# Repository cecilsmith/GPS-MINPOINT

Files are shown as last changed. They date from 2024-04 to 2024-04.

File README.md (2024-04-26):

# GPS-MINPOINT

This is the project folder for a Spring 2024 EE2361 Final Project.

## Hardware List

- Air530 GPS Module (connected via UART)
- PIC24 Microcontroller
- LCD for User Interaction
- LEDs for Debugging
- Printed/Milled Circuit Board for Components
- Enclosure for Electronics and Antenna
- Power Supply (3.3V)

## Software Requirements

- GPS driver ([`gps.h`](/2_Code/src/gps.h)/[`gps.c`](/2_Code/src/gps.c)) to interface with GPS module via UART
- UART driver ([`uart.h`](/2_Code/src/uart.h)/[`uart.c`](/2_Code/src/uart.c)) to handle communication with GPS module
- LCD driver ([`lcd.h`](/2_Code/src/lcd.h)/[`lcd.c`](/2_Code/src/lcd.c)) to handle communication with LCD module
- Mathematical Formulae ([`calculations.h`](/2_Code/src/calculations.h)/[`calculations.c`](/2_Code/src/calculations.c)) to find useful information from GPS coordinates
- General Use Functions ([`utils.h`](/2_Code/src/utils.h)/[`utils.c`](/2_Code/src/utils.c)) to contain non-standard, yet generally useful functions
- [`main.c`](/2_Code/src/main.c) to initialize hardware, call GPS driver to get location data, process data to find location

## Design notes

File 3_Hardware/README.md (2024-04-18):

# Hardware

This folder contains all work and documentation regarding the hardware. 

For this project, a custom PCB was designed using KiCAD. All footprints, schematics, and 3D files can be found under the `/lib/` folder.

### Current Design:
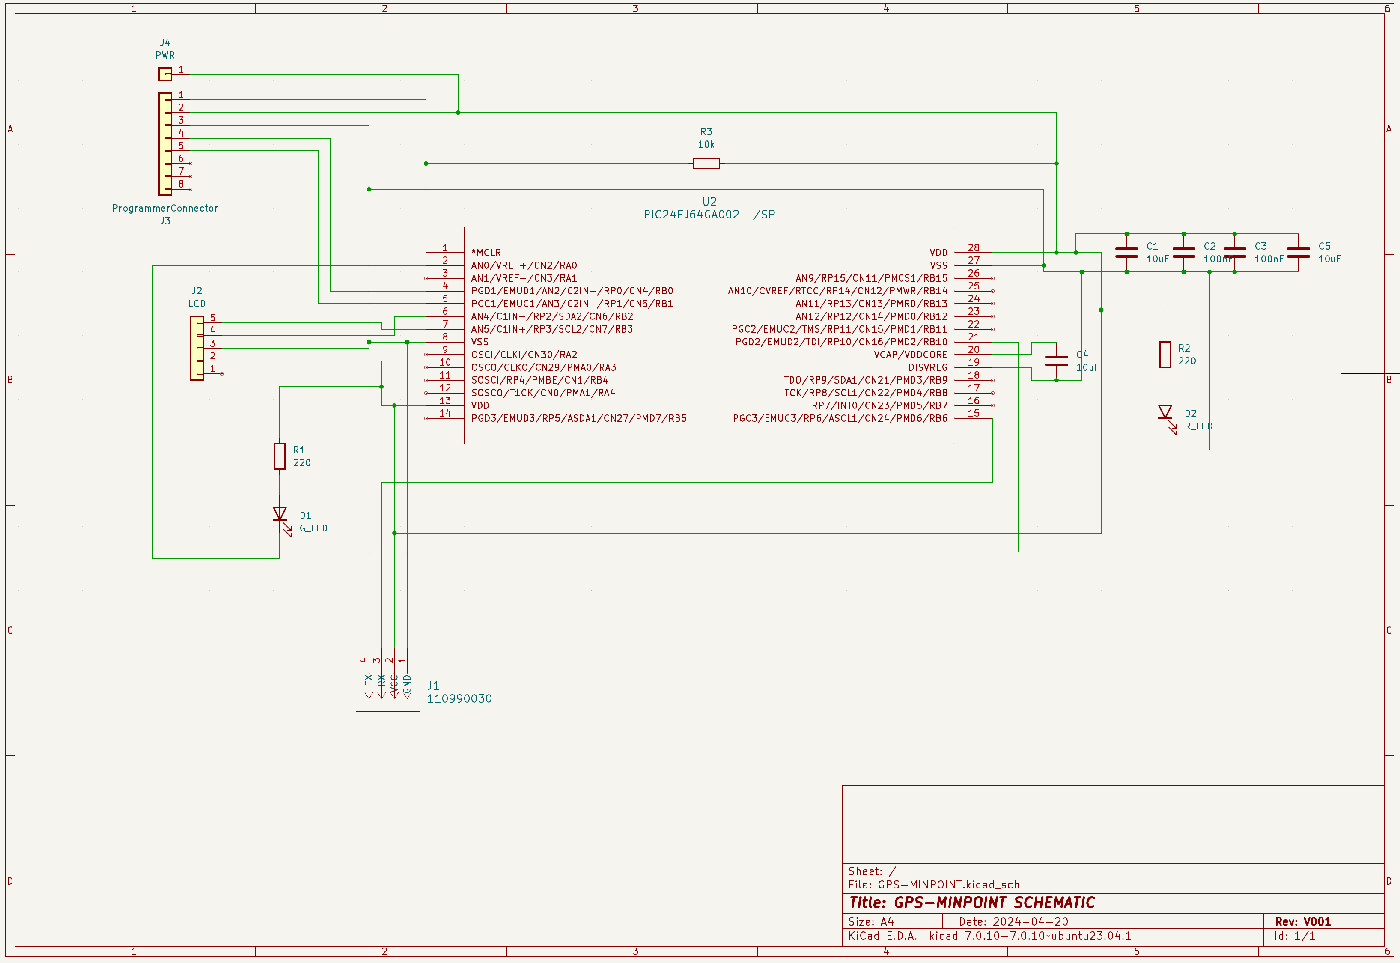
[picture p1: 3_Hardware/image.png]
Current Schematic Layout


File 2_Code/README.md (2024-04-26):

# Code

All source code for the project is located in this folder.

## Layout
- `/src` - Source code for the project.
  - `uart.h/uart.c` - UART driver.
  - `gps.h/gps.c` - GPS driver, uses UART driver.
  - `utils.h/utils.c` - General use functions
  - `calculations.h/calculations.c` - Reponsible for GPS distance and bearing calculation
  - `lcd.h/lcd.c` - LCD driver
  - `main.c` - Main file for the project.
- `/test` - Unit tests for the project.

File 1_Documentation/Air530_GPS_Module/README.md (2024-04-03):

# Air530 GPS Module

## Overview
The GPS module uses the NMEA protocol to communicate with the GPS receiver. This happens over a UART communication interface with the PIC24.

Based on the provided data sheets, the GPS module's UART runs at `9600 baud`.

## NMEA Protocol
The following link is a useful resource for understanding the NMEA protocol: [GPS NMEA](https://docs.arduino.cc/learn/communication/gps-nmea-data-101/)

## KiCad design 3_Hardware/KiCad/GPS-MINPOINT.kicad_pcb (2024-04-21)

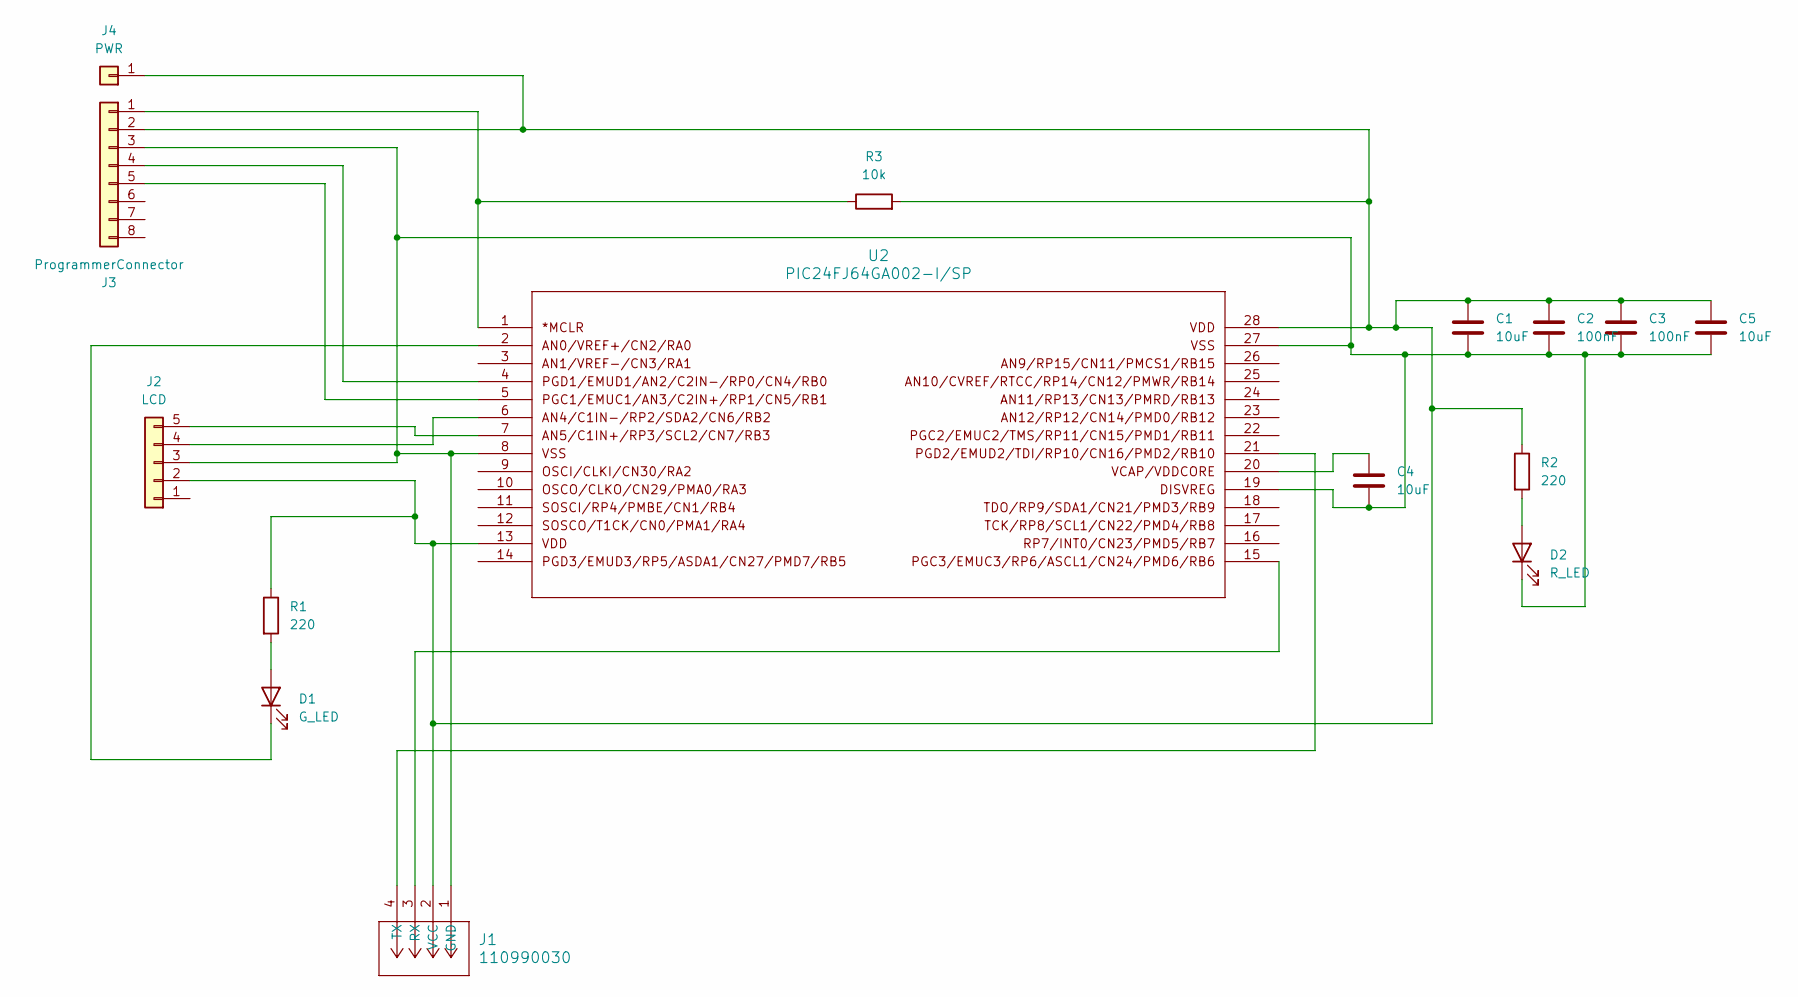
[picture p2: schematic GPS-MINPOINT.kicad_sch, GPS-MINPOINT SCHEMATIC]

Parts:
C1, C4, C5: 10uF; C_Disc_D4.7mm_W2.5mm_P5.00mm
C2, C3: 100nF; C_Disc_D4.7mm_W2.5mm_P5.00mm
D1: G_LED; LED_D3.0mm
D2: R_LED; LED_D3.0mm
J1: 110990030; CONN_110990030_SEE
J2: LCD; PinSocket_1x05_P2.54mm_Vertical
J3: ProgrammerConnector; PinHeader_1x08_P2.54mm_Vertical
J4: PWR; PinHeader_1x01_P2.54mm_Vertical
R1, R2: 220; R_Axial_DIN0207_L6.3mm_D2.5mm_P7.62mm_Horizontal
R3: 10k; R_Axial_DIN0207_L6.3mm_D2.5mm_P7.62mm_Horizontal
U2: PIC24FJ64GA002-I/SP; SPDIP28_300MC_MCH

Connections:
unnamed: C4.1, U2.20
unnamed: D1.2 (A), R1.2
unnamed: D1.1 (K), U2.2
unnamed: D2.2 (A), R2.2
unnamed: C1.2, C2.2, C3.2, C4.2, C5.2, D2.1 (K), J1.1 (GND), J2.3 (GND), J3.3, U2.8, U2.19, U2.27
unnamed: J1.3 (RX), U2.15
unnamed: J1.4 (TX), U2.21
unnamed: C1.1, C2.1, C3.1, C5.1, J1.2 (VCC), J2.2 (VDD), J3.2, J4.1, R1.1, R2.1, R3.2, U2.13, U2.28
unnamed: J2.5 (SCL), U2.7
unnamed: J2.4 (SDA), U2.6
unnamed: J3.1, R3.1, U2.1
unnamed: J3.4, U2.4
unnamed: J3.5, U2.5

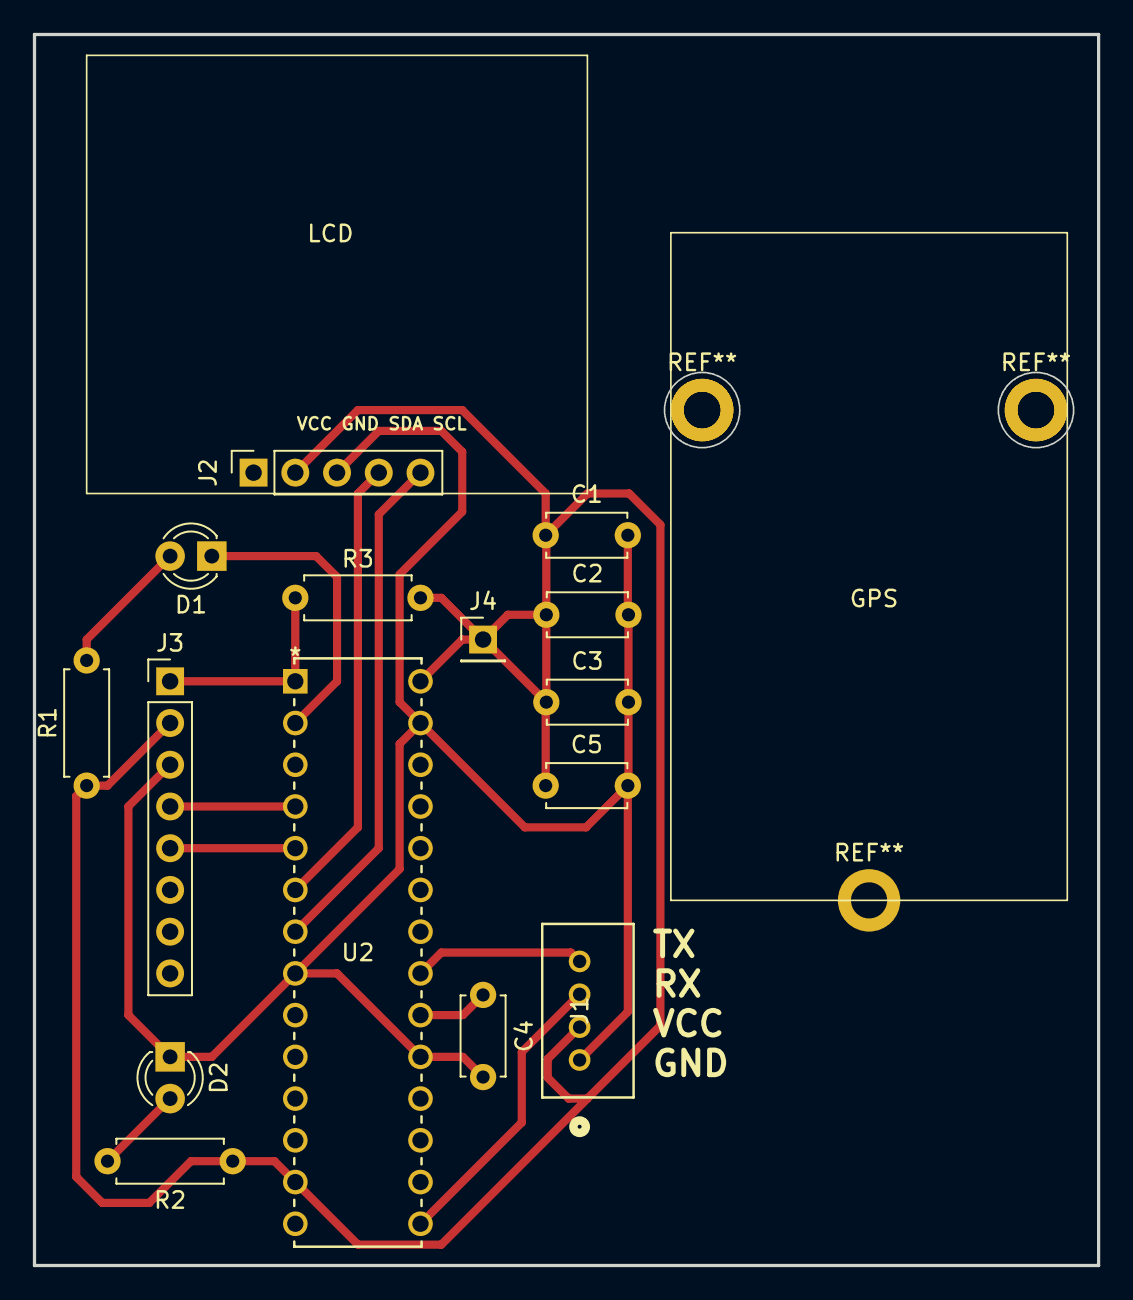
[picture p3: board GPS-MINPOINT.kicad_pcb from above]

Board: 2 copper layers, 64.8 x 74.9 mm, 15 parts (0 on the bottom side), 13 nets.

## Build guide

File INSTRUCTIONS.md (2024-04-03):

# GitHub Instructions

Here are the steps to use this repository with GitHub Desktop:

1. Install GitHub Desktop if you don't already have it:
   - Go to https://desktop.github.com/ and click on "Download for..." to download the version for your operating system.
   - Follow the installation prompts.

2. Clone the repository:
   - Open GitHub Desktop and click "File > Clone repository".
   - Enter the URL of this repository (`https://github.com/cecilsmith/GPS-MINPOINT.git`) and select a local path where you want the repository contents to be downloaded.
   - Click "Clone".
   
3. Make changes and commit:
   - Open the repository in your preferred text editor or IDE.
   - Make your changes to the files.
   - Go back to GitHub Desktop. You should see the changed files listed in the left panel.
   - If you haven't already, change your current branch to be something new/named after the changes you are working on--this will avoid accidental overwrites of the 'main' branch.
   - Enter a commit message summarizing your changes and then click "Commit to branch".
   
4. Push your changes:
   - In GitHub Desktop, click "Push origin" to push your committed changes to the remote repository on GitHub. 
   
5. Pull latest changes:
   - If someone else has modified the code click "Fetch origin" to retrieve them.
   - To merge the updates into your local repository, click "Pull origin".

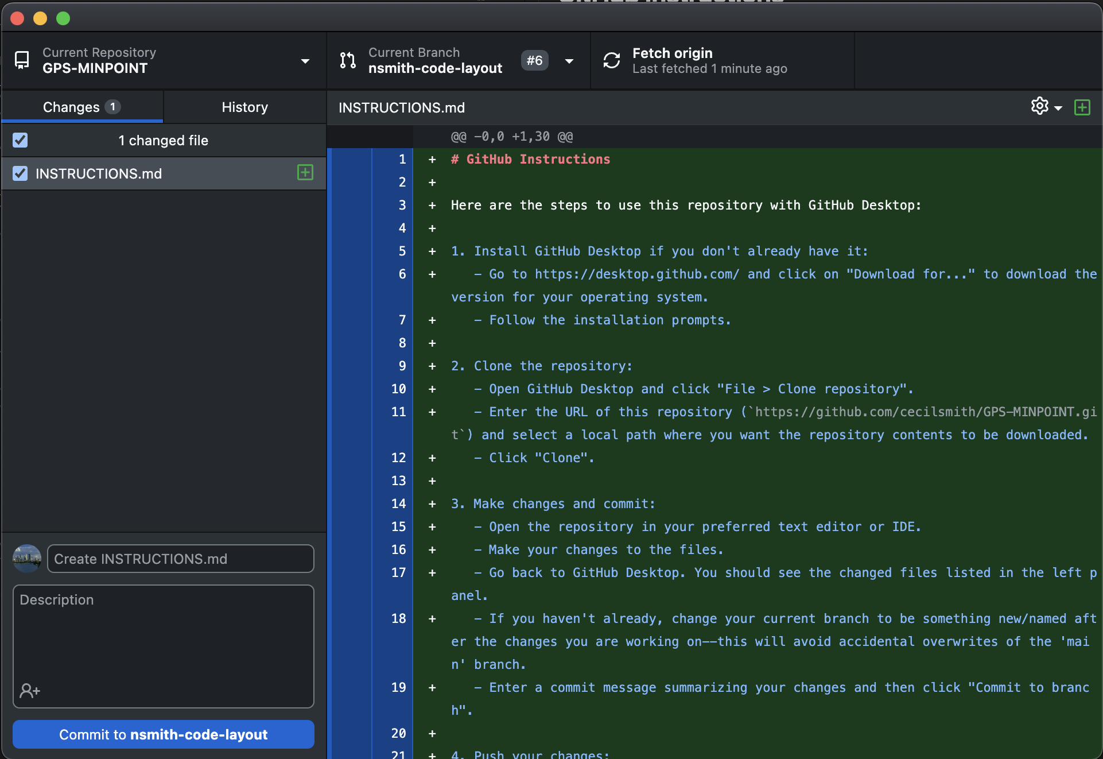
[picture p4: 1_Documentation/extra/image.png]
Sample window of GitHub Desktop


Now you have the repository on your local machine and can use GitHub Desktop to push and pull changes to sync with the remote repository on GitHub.

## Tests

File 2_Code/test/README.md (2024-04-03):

# Test

This folder is a designated spot for 'test code' to not clutter the main, `src` code.

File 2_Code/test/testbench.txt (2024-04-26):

Use this online compiler: https://www.onlinegdb.com/online_c_compiler
Copy and paste the code below:

#include <stdio.h>
#include <math.h>

// Global variables for current and destination coordinates
double currLatitude = 44.975755, currLongitude = -93.217189;
double destLatitude = 44.973828, destLongitude = -93.224746;

// Function to update current location (mocked for testing)
void getCurrentLocation(double* lat, double* lon) {
    *lat = currLatitude;
    *lon = currLongitude;
}

// Function to convert degrees to radians
double dToR(double degrees) {
    // Convert degrees to radians
    return degrees / 180.0 * M_PI;
}

// Function to calculate the distance between two points using Haversine formula
double distanceFinder() {
    // Radius of the Earth in kilometers
    const double R = 6371.0;

    // Convert latitude and longitude from degrees to radians
    double currLatRad = dToR(currLatitude);
    double currLonRad = dToR(currLongitude);
    double destLatRad = dToR(destLatitude);
    double destLonRad = dToR(destLongitude);

    // Haversine formula
    double dLat = destLatRad - currLatRad;
    double dLon = destLonRad - currLonRad;
    double a = sin(dLat / 2) * sin(dLat / 2) +
               cos(currLatRad) * cos(destLatRad) *
               sin(dLon / 2) * sin(dLon / 2);
    double c = 2 * atan2(sqrt(a), sqrt(1 - a));
    double distance = R * c;

    return distance;
}

int main() {
    // Calculate the distance to the destination
    double distance = distanceFinder();

    // Output the calculated distance
    printf("Distance to destination: %.2lf kilometers\n", distance);

    return 0;
}

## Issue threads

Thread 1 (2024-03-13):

Initial UART Library

cecilsmith, 2024-03-13:
In order to communicate with the Air530 GPS module, a UART library must be made. This library may be based off of in-class code and/or code found online for basic Serial communication.

When configuring the UART bus, a baud rate of `9600` will be used.
 The `TX` port of one device goes with the `RX` port of the other device.

_All images regarding Serial communication taken from [SparkFun](https://learn.sparkfun.com/tutorials/serial-communication/all): https://learn.sparkfun.com/tutorials/serial-communication/all_

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
Schematic of Serial/UART ports

If I'm not mistaken, UART uses _TTL serial signals_, this means that `HIGH` bits correspond to '1's and and `LOW` bits correspond to '0's in the bitstream. See the image below for endianness.

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

cecilsmith, 2024-03-22:
Using the datasheet of the PIC24, on page 163, we can find the setup registers for UART communication.

`BRGH`: Hight Baud Rate Enable Bit (0, 1)
`PDSEL`<1:0>:  Parity and Data Selection Bits:

* `11` = 9-bit data no parity
* `10` = 8-bit data, odd parity
* `01` = 8-bit data, even parity
* `00` = 8-bit data, no parity

`STSEL`: Stop Bit Selection Bit (`1`: Two Stop Bits, `0`: One Stop Bit)
`UARTEN`: UARTx Enable Bit (0, 1)

cecilsmith, 2024-03-22:
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

This of course, is using Peripheral Pin Select (PPS) for pin assignment.

cecilsmith, 2024-03-28:
I'm going to propose that we run our uC at 16 MHz.

Everything below has been shown in Discussion and/or around pg. 109 in the data sheet for PIC24 (specifically the PPS).

Using the equation for Baud Rate:
when `BRGH = 0`:

$UxBRG = \frac{Fcy}{16*Baud Rate}-1$

$UxBRG = \frac{16000000}{16*9600} - 1 = 103$

``` C
_TRISB6 = 0;  // U1TX output on RB6
_TRISB10 = 1; // U1RX input on RB10

U1MODE = 0;
U1MODEbits.BRGH = 0;
U1BRG = 103;
U1MODEbits.UEN = 0;
U1MODEbits.UARTEN = 0;
U1MODEbits.UTXEN = 1;

__builtin_write_OSCCONL(OSCCON & 0xBF); // unlock PPS
_RP6R = 0x0003;  // RB6->UART1:U1TX; Table 10-3 on pg. 109 of DS
_U1RXR = 10;         // RB10->UART1:U1RX;
__builtin_write_OSCCONL(OSCCON | 0x40); // lock   PPS

IFS0bits.U1RXIF = 0;
IEC0bits.U1RXIE = 1;
```

cecilsmith, 2024-04-09:
UART library written and merged into codebase,

Closed 2024-04-09.

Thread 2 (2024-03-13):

Schematic/Wiring Diagram for MINPOINT Package

cecilsmith, 2024-03-13:
Using the information listed in the datasheets for the PIC24 microcontroller, a schematic must be made of the system.

This schematic ought to include all of the following:
* Microcontroller (PIC24)
* GPS (Air530)
* 8 LEDs for Navigation
* 1 LED for Completion

We may have to use multiplexing for the output LEDs given the limited number of available output pins.

cecilsmith, 2024-03-13:
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

cecilsmith, 2024-04-05:
The first push of the schematic/PCB has been started under [this branch](https://github.com/cecilsmith/GPS-MINPOINT/tree/hardware-schematic/3_Hardware).

If you are looking to replicate this, remember to correctly import all library files under `/lib/`.

cecilsmith, 2024-04-22:
Completed.

Closed 2024-04-22.

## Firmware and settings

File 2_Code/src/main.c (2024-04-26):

/*
 * Course Number: EE2361
 * Term: Spring 2024
 * Lab/assignment number: Final Project
 * Short Program Description: Main function that initializes peripherals and runs navigation logic
 */

#include "xc.h" 
#include "uart.h"
#include "gps.h"
#include "lcd.h"
#include "calculations.h"
#include "utils.h"

#include <p24FJ64GA002.h>
#include <stdio.h>
#include <string.h>
#include "stdint.h"


// CW1: FLASH CONFIGURATION WORD 1 (see PIC24 Family Reference Manual 24.1)
#pragma config ICS = PGx1   // Comm Channel Select (Emulator EMUC1/EMUD1 pins are shared with PGC1/PGD1)
#pragma config FWDTEN = OFF // Watchdog Timer Enable (Watchdog Timer is disabled)
#pragma config GWRP = OFF   // General Code Segment Write Protect (Writes to program memory are allowed)
#pragma config GCP = OFF    // General Code Segment Code Protect (Code protection is disabled)
#pragma config JTAGEN = OFF // JTAG Port Enable (JTAG port is disabled)

// CW2: FLASH CONFIGURATION WORD 2 (see PIC24 Family Reference Manual 24.1)
#pragma config I2C1SEL = PRI  // I2C1 Pin Location Select (Use default SCL1/SDA1 pins)
#pragma config IOL1WAY = OFF  // IOLOCK Protection (IOLOCK may be changed via unlocking seq)
#pragma config OSCIOFNC = ON  // Primary Oscillator I/O Function (CLKO/RC15 functions as I/O pin)
#pragma config FCKSM = CSECME // Clock Switching and Monitor (Clock switching is enabled,
// Fail-Safe Clock Monitor is enabled)
#pragma config FNOSC = FRCPLL // Oscillator Select (Fast RC Oscillator with PLL module (FRCPLL))

#define FCY 16000000L // Define system clock frequency (16MHz)

extern volatile char moduleOutput[50];

/**
 * @brief Performs one-time setup operations for the application.
 *
 * This function is called once at the start of the program to perform
 * initialization tasks. It sets the RCDIV register to 0 to use the full
 * 16MHz clock, configures all pins as digital I/O, initializes Timer1
 * to generate a 1 second interrupt for the LCD, and starts the timer.
 */
void setup(void)
{
    // Execute once code goes here
    CLKDIVbits.RCDIV = 0; // Set RCDIV=1:1 (default 2:1) 32MHz or FCY/2=16M
    AD1PCFG = 0x9FFF;     // sets all pins to digital I/O

    TMR1 = 0;
    T1CON = 0;
    T1CONbits.TCKPS = 0b11;
    PR1 = 62499; // 1 second
    _T1IF = 0;
    T1CONbits.TON = 1;
    //    _T1IE = 0;
}

int main(int argc, char const *argv[])
{
    /* code */
    setup();
    init_UART(9600);
    initGPS();
    lcd_init();
    // Goldy Gopher Located at (44.97309399636732, -93.23485794557575)
    setTargetDestination(44.97309399636732, -93.23485794557575);
    delay_ms(1000);
    char LCD_flag = 0;
    while(1)
    {
        while(validateModuleOutput() == 0);
        delay_ms(750);

        char disStr[20];

        // Display latitude and longitude values on LCD if LCD_flag is true
        if (LCD_flag == 0)
        {
            double disValueLine1 = getLatitude();  // Get latitude value
            double disValueLine2 = getLongitude(); // Get longitude value

            lcd_setCursor(0, 0); // Set cursor to line 1

            if (disValueLine1 < 0)
            {
                sprintf(disStr, "%7.3fS", (-1 * disValueLine1)); // Format negative latitude
            }
            else
            {
                sprintf(disStr, "%7.3fN", disValueLine1); // Format positive latitude
            }

            lcd_printStr(disStr); // Print formatted latitude

            lcd_setCursor(0, 1); // Set cursor to line 2
            if (disValueLine2 < 0)
            {
                sprintf(disStr, "%7.3fW", (-1 * disValueLine2)); // Format negative longitude
            }
            else
            {
                sprintf(disStr, "%7.3fE", disValueLine2); // Format positive longitude
            }
            lcd_printStr(disStr); // Print formatted longitude
            LCD_flag++;
        }
        else if (LCD_flag == 1)
        {

            // Display distance value on LCD if LCD_flag is false

            lcd_setCursor(0, 0);      // Set cursor to line 1
            lcd_printStr("DISTANCE"); // Print header

            double disValueLine2 = distanceFinder(); // Get distance value

            if (disValueLine2 > 10000)
            {
                sprintf(disStr, "%6.1fkm", (float)(disValueLine2 / 1000.00)); // Format distance in km
            }
            else
            {
                sprintf(disStr, "%7.1fm", disValueLine2); // Format distance in m
            }

            lcd_setCursor(0, 1);  // Set cursor to line 2
            lcd_printStr(disStr); // Print formatted distance
            LCD_flag++;
        }
        else
        {
            // Display bearing value on LCD if LCD_flag is false

            lcd_setCursor(0, 0);     // Set cursor to line 1
            lcd_printStr("BEARING "); // Print header

            double disValueLine2 = bearingFinder(); // Get bearing value

            sprintf(disStr, "%3dDeg%c%c", (int)disValueLine2, bearingDirection(disValueLine2)[0], bearingDirection(disValueLine2)[1]); // Format bearing value

            lcd_setCursor(0, 1);  // Set cursor to line 2
            lcd_printStr(disStr); // Print formatted distance
            LCD_flag = 0;
        }
    }
    return 0;
}

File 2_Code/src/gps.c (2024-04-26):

/*
 * Course Number: EE2361
 * Term: Spring 2024
 * Lab/assignment number: Final Project
 * Short Program Description: Contains functions related to obtaining and formatting GPS data from the Grove - Air530 Module.
 */

#include "xc.h"
#include <stdio.h>
#include <string.h>
#include <stdlib.h>
#include "gps.h"
#include "uart.h"
#include "utils.h"

// Initialize the GPS's date with this!
// In "year,month,day" format.
char *initialDate = "2024,4,25";

// Initialize the GPS's position with this!
// Within 6 decimal points of precision, and no
// spaces between commas
char *initialLatitudeLongitude = "45.181479,-93.224900"; // Keller Hall: ("45.181479,-93.224900")

// This string is used to store commands that are 
// outputted by the module.
volatile char moduleOutput[50];

/**
 * @brief Initializes the GPS module with the necessary settings.
 *
 * This function sets up the UART communication, performs a cold start on the GPS module,
 * configures the GPS to single mode, sets the NMEA output rate, selects the GPS as the
 * desired GNSS, sets the baud rate, enables SBAS, and outputs the GLL and GST NMEA
 * sentences. It also calls the `initLocationAndTime()` function to speed up cold starts.
 */
void initGPS(void)
{
    // Initializes the GPS with its relevant settings

    // Set up UART
    init_UART(9600);

    // Set up GPS
    delay_ms(50);
    send_GPS_Str_command("$PGKC030,3,1*2E\r\n"); // System cold start
    delay_ms(10);
    send_GPS_Str_command("$PGKC115,1,0,0,0*2B\r\n"); // Single GPS Mode (we're not going international)
    delay_ms(30);
    send_GPS_Str_command("$PGKC101,500*36\r\n"); // Output NMEA messages every 0.5 seconds
    delay_ms(10);
    send_GPS_Str_command("$PGKC115,1,0,0,0*2B\r\n"); // Set the desired GNSS to GPS
    delay_ms(10);
    send_GPS_Str_command("$PGKC147,9600*0E\r\n"); // Set the baudrate to 9600
    delay_ms(10);
    send_GPS_Str_command("$PGKC149,0,9600*1C\r\n"); // Set the serial ports to accept NMEA data at 9600 bps
    delay_ms(10);
    send_GPS_Str_command("$PGKC239,1*3A\r\n"); // Turns SBAS on (improves accuracy)
    delay_ms(30);
    send_GPS_Str_command("$PGKC242,1,0,0,0,0,0,0,0,0,0,0,0,0,0,0,0,0,0,0*36\r\n"); // output GLL and GST
    delay_ms(30);
    initLocationAndTime(); // Speeds up cold starts
    initModuleOutput();
}

/**
 * Initializes the location and time information for the GPS module.
 * This function constructs a NMEA command string with the initial latitude, longitude, and date, calculates the checksum, and sends the command to the GPS module.
 */
void initLocationAndTime(void)
{
    char hexSum[3]; // Need space for two characters and null terminator
    char templateCmd[83] = "$PGKC639,";

    strcat(templateCmd, initialLatitudeLongitude); // Assuming initialLatitudeLongitude is a null-terminated string
    strcat(templateCmd, ",0,");
    strcat(templateCmd, initialDate); // Assuming initialDate is a null-terminated string
    strcat(templateCmd, ",0,0,0*");

    // Calculate checksum and format it as hexadecimal
    sprintf(hexSum, "%02X", checkSum(templateCmd));

    strcat(templateCmd, hexSum);
    strcat(templateCmd, "\r\n");

    // Send the constructed NMEA command
    send_GPS_Str_command(templateCmd);
}

/**
 * Computes the checksum of a command string by XORing all the character values.
 * The checksum is calculated starting from the first character after the '$' character.
 * The checksum calculation stops when the '\0' or '*' character is encountered.
 *
 * @param cmd The command string to compute the checksum for.
 * @return The computed checksum.
 */
int checkSum(char *cmd)
{
    // Compute the checksum by XORing all the character values in the string.
    unsigned int checksum = 0;
    int beginRecordingCheckSum = 0;
    while (*cmd != '\0')
    {
        if (beginRecordingCheckSum == 1)
        {
            checksum ^= *cmd;
        }

        if (*cmd == '$')
        {
            beginRecordingCheckSum = 1;
        }

        cmd++; // Move to the next character in the string

        if (*cmd == '*')
        {
            return checksum;
        }
    }
    return checksum;
}

/**
 * Returns the latitude direction ('N' or 'S') based on the GPS module output.
 * @return The latitude direction as a character ('N' or 'S').
 */
char getLatitudeDirection(void)
{
    return moduleOutput[18];
}

/**
 * Returns the longitude direction ('E' or 'W') based on the GPS module output.
 * @return The longitude direction as a character ('E' or 'W').
 */
char getLongitudeDirection(void)
{
    return moduleOutput[32];
}

/**
 * Calculates the latitude value from the GPS module output.
 *
 * This function extracts the latitude value from the GPS module output string and
 * converts it to a floating-point value. It handles the conversion from degrees,
 * minutes, and seconds to a decimal latitude value, and applies the appropriate
 * sign based on the latitude direction (North or South).
 *
 * @return The latitude value as a double.
 */
double getLatitude()
{
    // Check that the GPS module output is valid before parsing
    while (!(validateModuleOutput()))
        ;
    double latitude = 0;
    char minutes[8];

    latitude += (moduleOutput[7] - '0') * 10;
    latitude += (moduleOutput[8] - '0');

    // Floating point operations are extremely annoying to deal with
    // To preserve precision, an array is used
    minutes[0] = (moduleOutput[9]);
    minutes[1] = (moduleOutput[10]);
    minutes[2] = (moduleOutput[11]);
    minutes[3] = (moduleOutput[12]);
    minutes[4] = (moduleOutput[13]);
    minutes[5] = (moduleOutput[14]);
    minutes[6] = (moduleOutput[15]);
    minutes[7] = (moduleOutput[16]);

    // Convert minutes string to double
    double extractedMinutes = atof(minutes);
    // Add minutes to degrees
    latitude += (extractedMinutes / 60);

    // If lat dir is south, negate value
    if (getLatitudeDirection() == 'S')
    {
        latitude *= -1;
    }
    return latitude;
}
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

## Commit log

2024-03-29 updates to home README and uart.c
2024-04-05 initial schematic push
    [GPS-MINPOINT.kicad_pcb, GPS-MINPOINT.kicad_sch]
2024-04-08 Implementations of the suggestions
    I have changed the baudrate calculation so that we can enter 9600 and it automatically calculates it to 103.
    I have also added the unsigned int before baudrate. I was wondering why it was giving an error lol.
    as for the setup/init pin initialization, i removed setting all pins to digital and just kept setting the pins we need (_TRISB6 = 0; _TRISB10 = 1;)
    as for back &= 63, that was originally copied from the discussion to implement a circular buffer. however, it didn't work when i tried implementing it in my lab so i have upddated it to a version that works and is self explanatory.
    Finally, I have added a string getter. It requires a pointer string and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
    [uart.c]
2024-04-08 Small fix of the void
    I have changed the unsigned char to void on that one function we looked at together.
    [uart.c]
2024-04-11 Remade get string function
    remade the get string function so we can always just pull the entire string and you know what the size of the string is too. Also increased the buffer size to 170 so there should be less of a worry t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
2024-04-12 Fixed header file
    My bad oopsies
    [uart.c]
2024-04-12 Fixed errors caught by MPLABX. Setup a main function for debugging purposes.
    [gps.c, main.c, uart.c]
2024-04-20 Upload of finished PCB design
    [GPS-MINPOINT-B_Cu.gbr, GPS-MINPOINT-B_Mask.gbr, GPS-MINPOINT-B_Paste.gbr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]
2024-04-22 Fully working uart.c and gps.c. Extensively tested and debugged.
    Fully working uart.c and gps.c. Extensively tested and debugged.
2024-04-23 Fixed hardware issues
    Update
    [gps.c, main.c, uart.c]
2024-04-24 Other files (gps,uart,main)
    Changes to other files to fit the LCD file. Suggested main structure to work, needs some editing to display correctly
    [gps.c, main.c]
2024-04-25 small update to fix errors
    [lcd.c, main.c]
2024-04-25 Fixed calculations to include bearing finder
    [calculations.c]
2024-04-25 Updates and bearing
2024-04-26 Fixed distance calculator
    Accurate to 2 feet now
    [calculations.c, gps.c, main.c]
2024-04-26 fixed empty character thing and also dkm
    [main.c, uart.c]
2024-04-26 bearing calculation and 3rd LCD screen.
